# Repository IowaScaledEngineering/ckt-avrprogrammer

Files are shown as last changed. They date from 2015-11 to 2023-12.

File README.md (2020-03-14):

# Iowa Scaled Engineering CKT-AVRPROGRAMMER

The [CKT-AVRPROGRAMMER](https://www.iascaled.com/store/CKT-AVRPROGRAMMER) is
a modification on the various USBtinyISP Atmel/Microchip AVR programmers,
such as the [SparkFun Pocket AVR Programmer](https://www.sparkfun.com/products/9825) 
and [Adafruit USPtinyISP AVR Programmer](https://www.adafruit.com/product/46). 
We wanted a version with the ability to power both 3.3V and 5V targets, and
short protection to avoid taking down the USB chain in the event of a target
short.

https://www.iascaled.com/store/CKT-AVRPROGRAMMER

## Hardware

Hardware portions of this project were created by Nathan Holmes and 
Michael Petersen of Iowa Scaled Engineering, LLC, and licensed under 
the Creative Commons Attribution-ShareAlike License.  Details of this 
license can be found here:
https://creativecommons.org/licenses/by-sa/3.0/us/

Much of this design was inspired by SparkFun's Pocket AVR Programmer, 
which itself is open hardware and licensed under CC ShareAlike:
https://www.sparkfun.com/products/9825

Source files (found in sch/ and sym/ for the schematic and pcb/ for the pcb)
are in gEDA (gschem / pcb) format.

Production versions are archived in the pg/ directory, and include PDFs of
the schematics and PCB files, as well as the actual gerbers used for board
and stencil generation.

## Software

Source code can be found in the src/ subdirectory.  The firmware in the pocket-prog directory originally came from Sparkfun's
Pocket AVR Programmer project on GitHub:

https://github.com/sparkfun/Pocket_AVR_Programmer

This was, in turn, based on the USBtiny by Dick Streefland, and USBtinyISP
by Limor Fried.

http://dicks.home.xs4all.nl/avr/usbtiny/index.html

https://learn.adafruit.com/usbtinyisp

This code, per Dick Streefland's original license, is free software licensed
under the GNU General Public License v2.  For a copy of the GPL v2, see the 
src/LICENSE file.

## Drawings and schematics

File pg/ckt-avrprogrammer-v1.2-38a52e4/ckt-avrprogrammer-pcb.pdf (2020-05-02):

# ckt-avrprogrammer.pcb

# 1. Table of Contents (This Page) Created on Wed Apr 15 09:13:26 2020

# 2. top 3. bottom 4. outline 5. plated-drill 6. unplated-drill 7. componentmask 8. soldermask 9. topsilk 10. bottomsilk 11. toppaste 12. topassembly 13. bottomassembly 14. fab

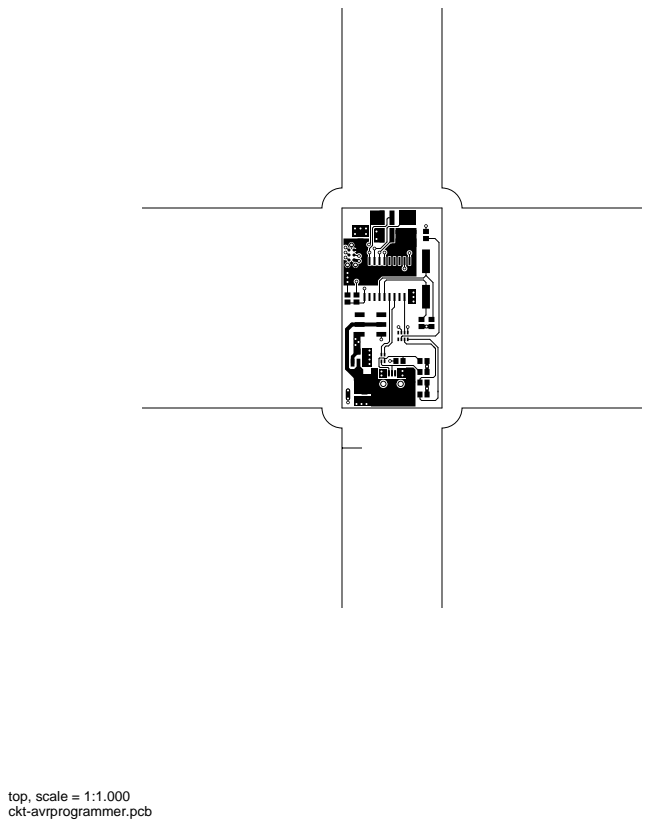
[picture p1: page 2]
top, scale = 1:1.000

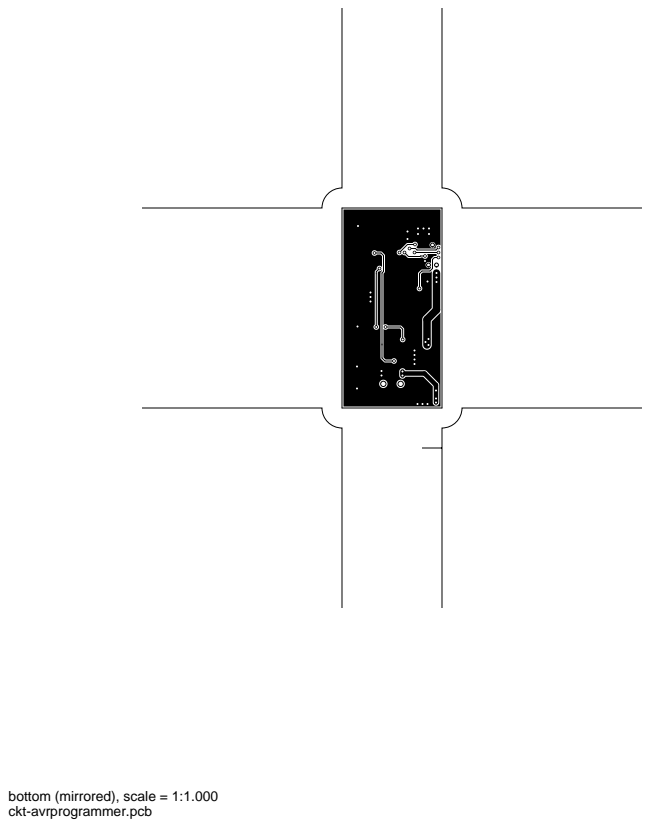
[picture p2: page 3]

bottom (mirrored), scale = 1:1.000

outline, scale = 1:1.000

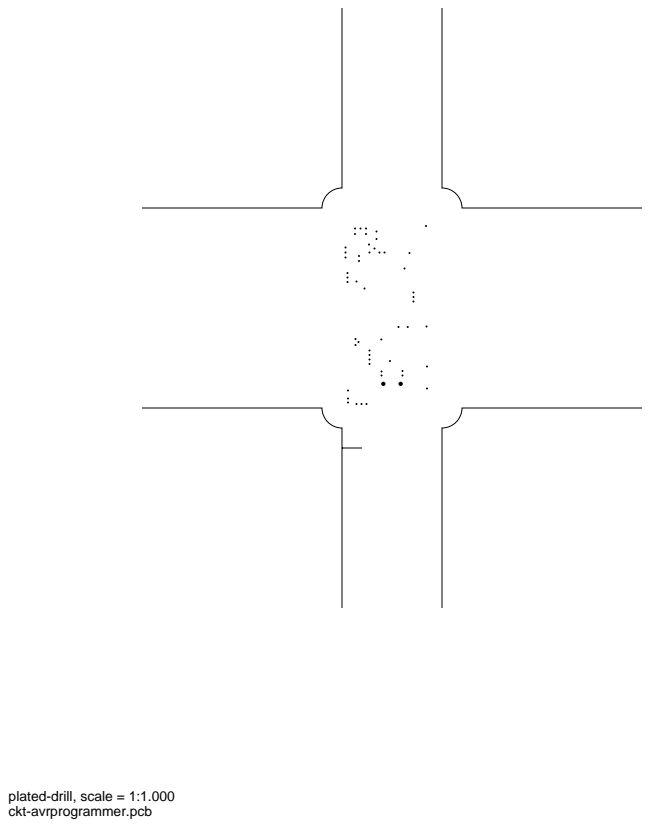
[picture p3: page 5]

plated-drill, scale = 1:1.000

unplated-drill, scale = 1:1.000

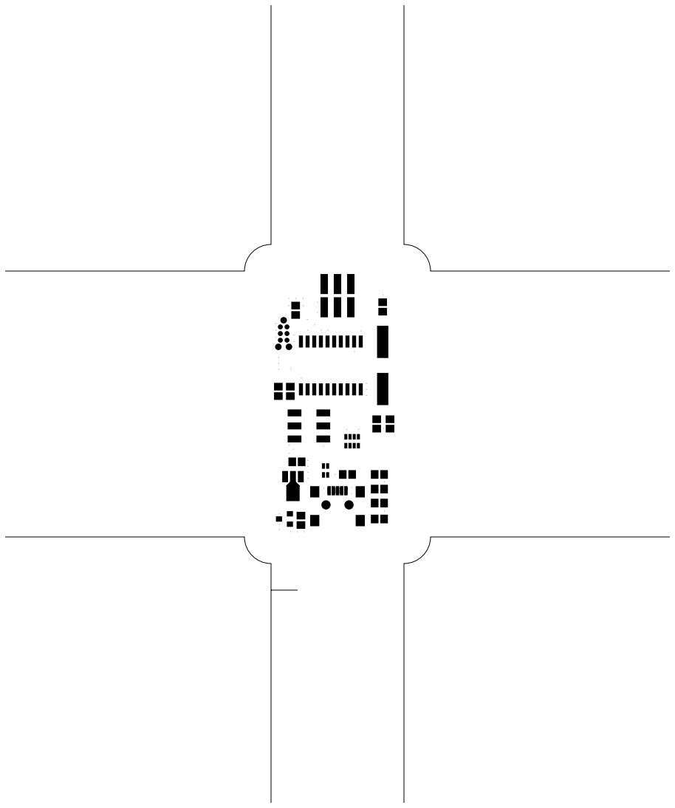
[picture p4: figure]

topmask, scale = 1:1.000

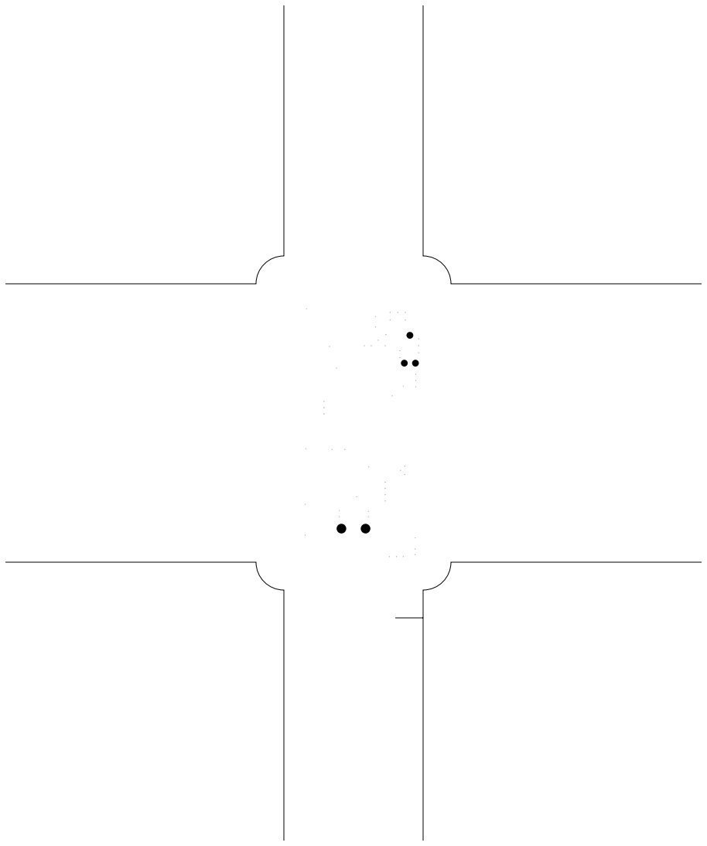
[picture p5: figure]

bottommask (mirrored), scale = 1:1.000

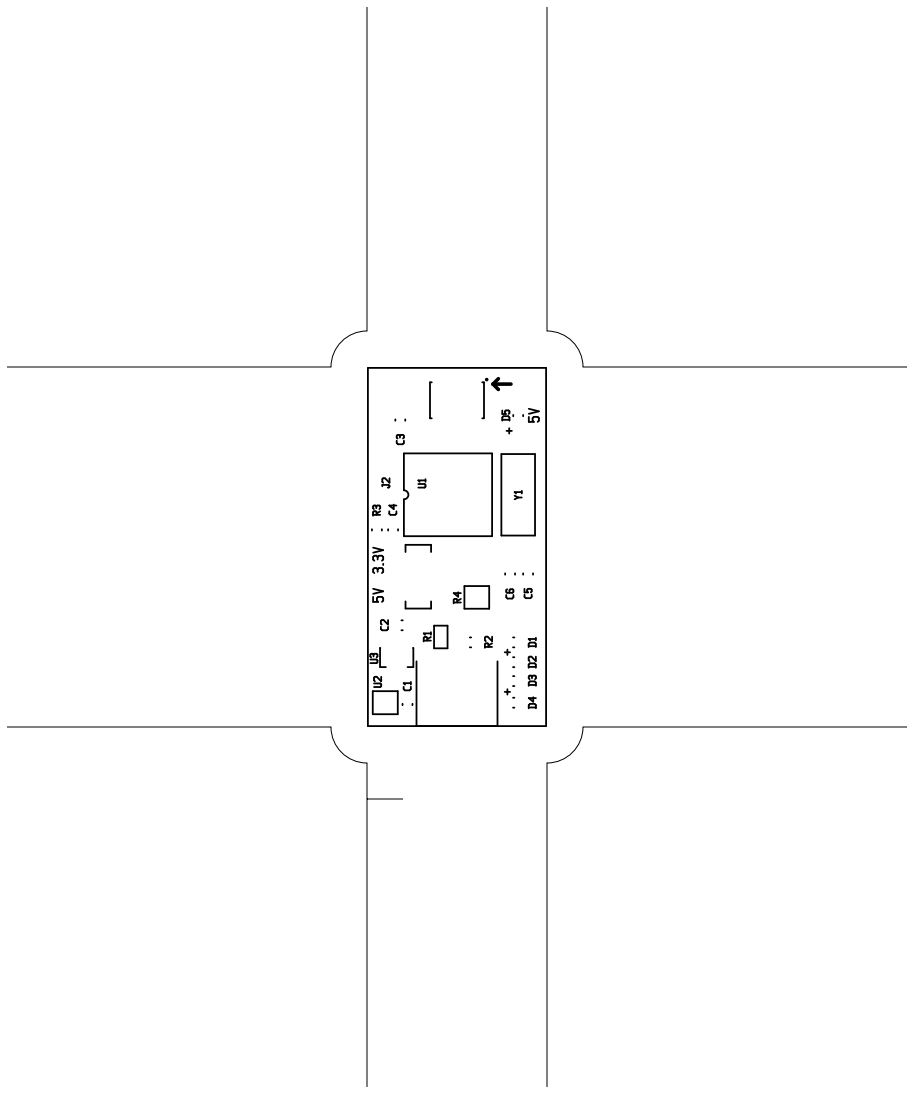
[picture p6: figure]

topsilk, scale = 1:1.000

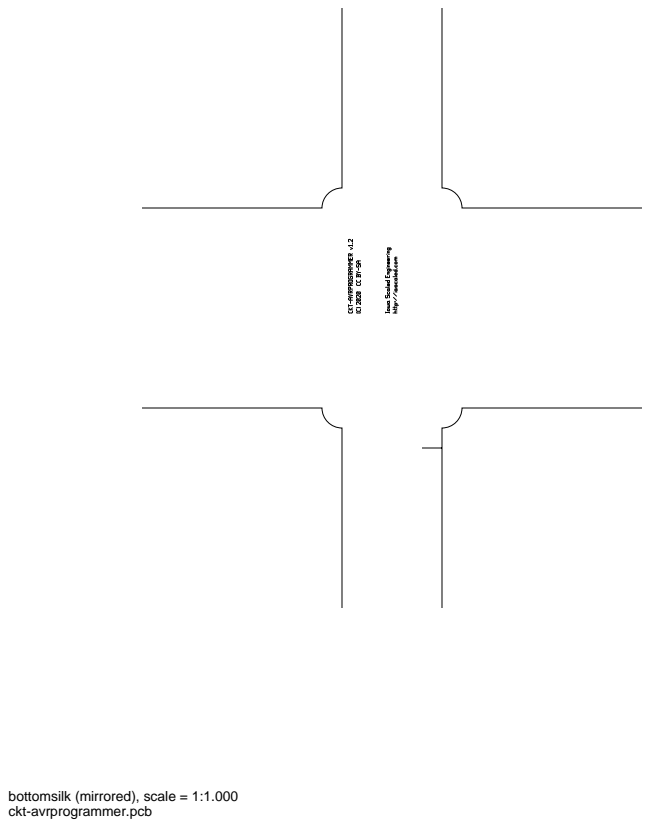
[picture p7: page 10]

bottomsilk (mirrored), scale = 1:1.000

toppaste, scale = 1:1.000

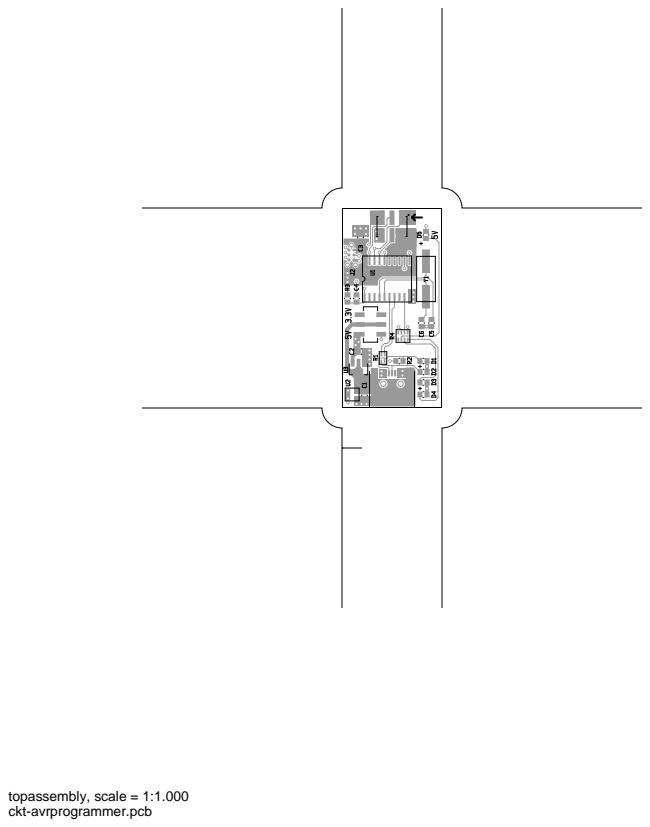
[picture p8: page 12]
topassembly, scale = 1:1.000

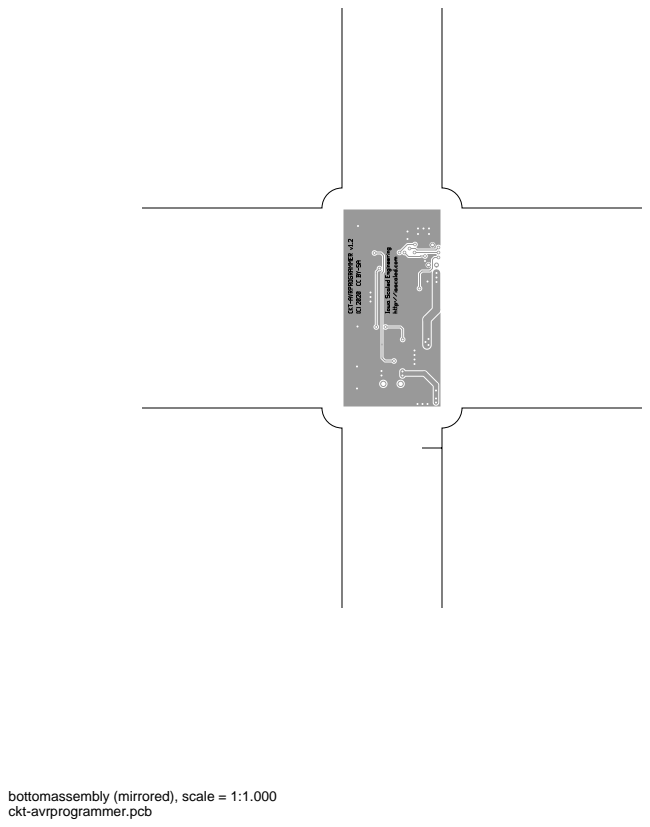
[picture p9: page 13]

bottomassembly (mirrored), scale = 1:1.000

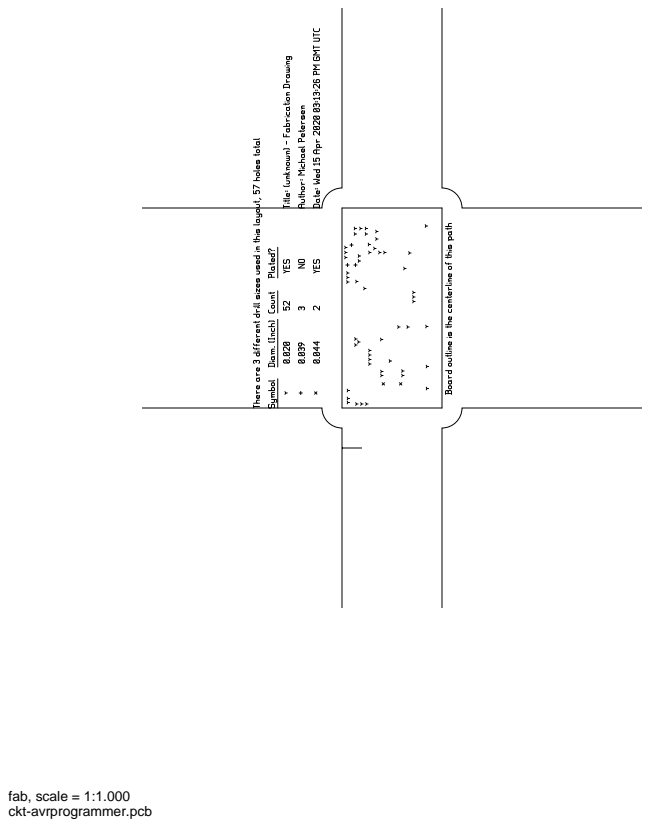
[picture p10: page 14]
fab, scale = 1:1.000

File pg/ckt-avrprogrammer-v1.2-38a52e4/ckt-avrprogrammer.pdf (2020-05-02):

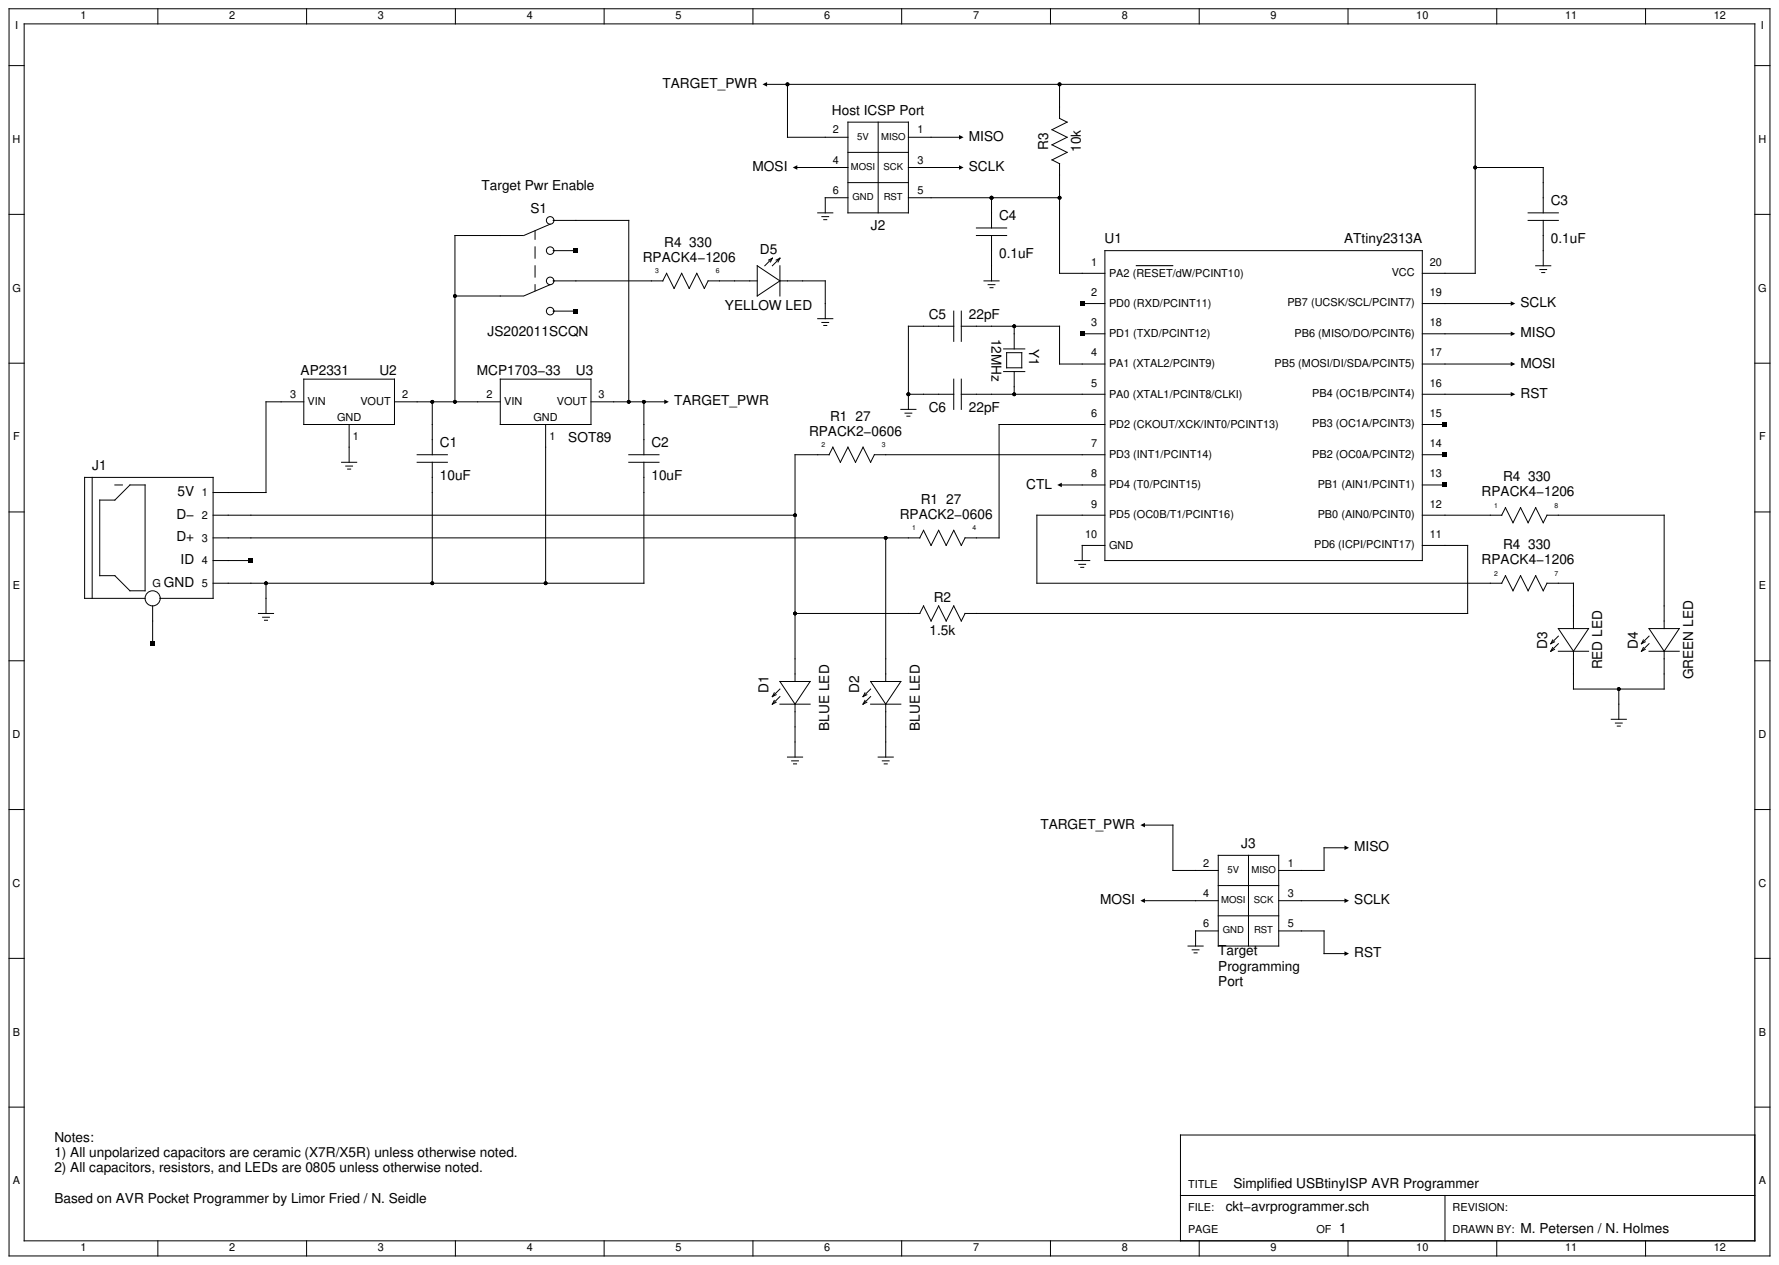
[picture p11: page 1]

8 CTL | 13

Notes:
1) All unpolarized capacitors are ceramic (X7R/X5R) unless otherwise noted.
2) All capacitors, resistors, and LEDs are 0805 unless otherwise noted.

Simplified USBtinyISP AVR Programmer
ckt−avrprogrammer.sch

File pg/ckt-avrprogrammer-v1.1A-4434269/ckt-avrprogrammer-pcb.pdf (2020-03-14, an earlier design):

# ckt-avrprogrammer.pcb

# 1. Table of Contents (This Page) Created on Thu Aug 30 13:28:31 2018

# 2. top 3. bottom 4. outline 5. plated-drill 6. unplated-drill 7. componentmask 8. soldermask 9. topsilk 10. bottomsilk 11. toppaste 12. topassembly 13. bottomassembly 14. fab

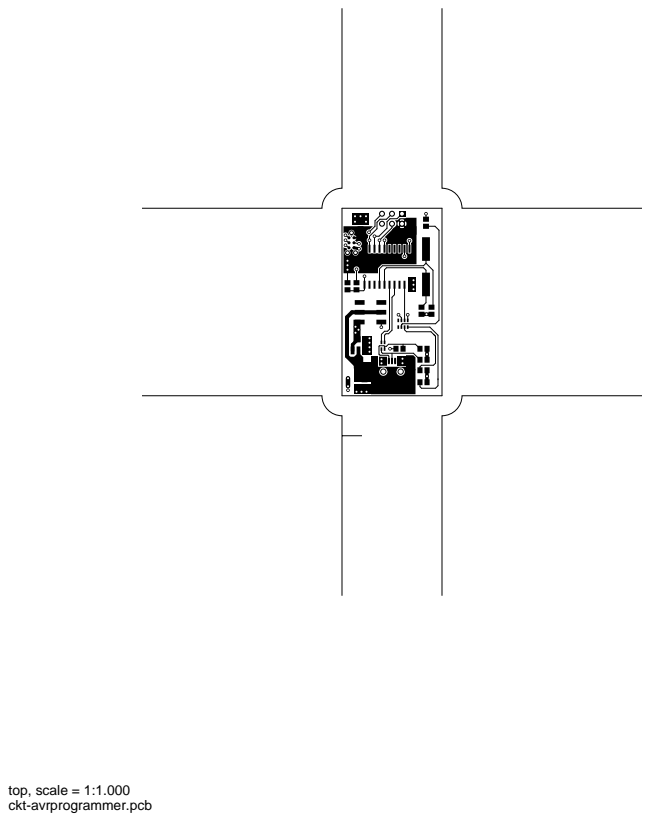
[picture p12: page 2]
top, scale = 1:1.000


bottom (mirrored), scale = 1:1.000

outline, scale = 1:1.000


plated-drill, scale = 1:1.000

unplated-drill, scale = 1:1.000


topmask, scale = 1:1.000


bottommask (mirrored), scale = 1:1.000


topsilk, scale = 1:1.000


bottomsilk (mirrored), scale = 1:1.000

toppaste, scale = 1:1.000

topassembly, scale = 1:1.000


bottomassembly (mirrored), scale = 1:1.000

fab, scale = 1:1.000

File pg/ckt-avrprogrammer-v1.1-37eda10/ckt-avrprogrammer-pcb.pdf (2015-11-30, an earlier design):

# ckt-avrprogrammer.pcb

# 1. Table of Contents (This Page) Created on Mon Nov 30 11:11:34 2015

# 2. top 3. bottom 4. outline 5. plated-drill 6. unplated-drill 7. componentmask 8. soldermask 9. topsilk 10. bottomsilk 11. toppaste 12. topassembly 13. bottomassembly 14. fab

top, scale = 1:1.000


bottom (mirrored), scale = 1:1.000

outline, scale = 1:1.000


plated-drill, scale = 1:1.000

unplated-drill, scale = 1:1.000


topmask, scale = 1:1.000


bottommask (mirrored), scale = 1:1.000


topsilk, scale = 1:1.000


bottomsilk (mirrored), scale = 1:1.000

toppaste, scale = 1:1.000

topassembly, scale = 1:1.000


bottomassembly (mirrored), scale = 1:1.000

fab, scale = 1:1.000

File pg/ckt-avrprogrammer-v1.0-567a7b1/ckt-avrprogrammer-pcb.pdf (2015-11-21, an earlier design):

# ckt-avrprogrammer.pcb

# 1. Table of Contents (This Page) Created on Thu Oct 29 12:01:01 2015

# 2. top 3. bottom 4. outline 5. plated-drill 6. unplated-drill 7. componentmask 8. soldermask 9. topsilk 10. bottomsilk 11. toppaste 12. topassembly 13. bottomassembly 14. fab

top, scale = 1:1.000


bottom (mirrored), scale = 1:1.000

outline, scale = 1:1.000


plated-drill, scale = 1:1.000

unplated-drill, scale = 1:1.000


topmask, scale = 1:1.000


bottommask (mirrored), scale = 1:1.000


topsilk, scale = 1:1.000


bottomsilk (mirrored), scale = 1:1.000

toppaste, scale = 1:1.000

topassembly, scale = 1:1.000


bottomassembly (mirrored), scale = 1:1.000

fab, scale = 1:1.000

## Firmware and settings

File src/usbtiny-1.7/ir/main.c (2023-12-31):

// ======================================================================
// IR receiver and LCD controller with USB interface.
//
// Read IR mark/space patterns from a TSOP1738 on the ICP input pin.
// Mark and space periods are measured in units of 12Mhz/1024, which is
// 85.33 us. Up to 36 periods are stored in a buffer, where they can
// be read via a USB request. The buffer layout and USB requests are
// compatible with the "IgorPlug-USB" device, which is supported by LIRC
// through the "igorplugusb" driver. This implementation should also
// work with that driver. If IgorPlug-USB compatibility is not required,
// the resolution could be improved by reducing SCALING to 9, and you
// could also get rid of the additional endpoint (USBTINY_ENDPOINT).
//
// There are some IR protocols with very long packets length, such as
// the "NEC" protocol (http://www.sbprojects.com/knowledge/ir/nec.htm).
// This protocol uses 67 mark/space periods, which is too much for the
// limited amount of RAM in the ATtiny2313. Simply truncating the
// packet to the amount of available buffer space is not an option,
// because the significant bits are at the end of the packet. Instead,
// a buffer of 36 bytes (IR_MAX) is used, of which the last 16 bytes
// (IR_WRAP) are used as a circular buffer. Because both the address
// (16 periods) and the command code (16 periods) are sent twice (normal
// and inverted), the wrapping will result in a buffer with both the
// device address and the inverted command code. Other IR protocols are
// typically shorter than 36 periods.
//
// 16-bit Timer1 is initialized in normal mode with a clock of 12MHz/8.
// Both the positive and negative edges of the IR input signal on the
// ICP input pin trigger an input capture interrupt, because the edge
// selection is toggled on every interrupt. Output compare register A
// is used for a timeout to detect the end of an IR transmission.
// The timeout value is updated on every edge. When at least 4 edges
// were detected when a timeout occurs, the packet count ir.count is
// incremented and the ir.length byte is set to the packed length. This
// byte is checked when a read request is received via USB to see if a
// packet is available
//
// The two interrupt handlers in this file run for more than 28 cycles,
// so they need to reenable interrupts to allow USB interrupts to be
// handled in time. To avoid nested IR interrupts, the input capture and
// output compare interrupts are disabled before the global interrupt
// flag is set. In the input capture interrupt handler, the interrupts
// are disabled for a maximum of 27, 27 and 27 cycles, and in the output
// compare interrupt handler for 21, 23 and 22 cycles. Unfortunately,
// it was not possible to meet the 28 cycle maximum for the input
// capture interrupt handler without using some inline assembly.
// Because the limits are so tight, the code is fragile, and may break
// for a new gcc version.
//
// The IR receiver is disabled during an IR buffer read, so that a
// packet that is being tranmitted to the host, is not overwritten by
// the next packet. When a transfer is in progress, 'inpos' has a value
// other than 0xff. When the buffer is read completely, the IR receiver
// is reenabled again, but when the next IR packet has already started,
// this packed is discarded by setting 'edges' to 0xff.
//
// There are two USB request codes to control the LCD, one to write
// instructions, and one to write data to the display. OUT transfers
// are used to transfer up to 255 bytes for a single request.
//
// Stack space calculations for gcc-4.1.0 and gcc-4.3.4:
//
//   0  main (stack reset)
//   0      lcd_init (inlined)
//   0      ir_init (inlined)
//   2      usb_init
//   5      usb_poll
//   0          usb_receive (inlined)
//   2              usb_setup
//   5              usb_out
//   3                  lcd_write
//   0                      lcd_read4 (inlined)
//   2                      lcd_write4
//   0          usb_transmit (inlined)
//   4              usb_int
//   2              crc
//
// Maximum stack space is 5+5+3+2=15.
// Total stack usage:
// - USB interrupt:			11 bytes
// - IR input capture interrupt:	12 bytes
// - IR output compare interrupt: 	 7 bytes
// - main():				15 bytes
// The two IR interrupt handler cannot be active simultaneously, so the
// maximum stack space is 15+12+11=38 bytes.
//
// NOTE: The above cycle and stack size figures were obtained by
//       inspecting the code generated by gcc-4.1.0 and gcc-4.3.4.
//       Other compiler versions may generate different code, leading
//       to different figures.
//
// Copyright 2006-2010 Dick Streefland
//
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
#include <avr/io.h>
#include <avr/interrupt.h>
#include "def.h"
#include "usb.h"

// ----------------------------------------------------------------------
// IR receiver definitions
// ----------------------------------------------------------------------

#define	TIMEOUT		10500	// IR transmission timeout in us
#define	IR_MAX		36	// maximum number of IR data bytes
#define	IR_WRAP		16	// wrap area at end (for 67 byte NEC protocol)
#define	SCALING		10	// 9: 42.67 us period, 10: 85.33 us period
#define	LED		(D,5)	// I/O port for LED

enum
{
	// Generic requests
	USBTINY_ECHO,		// echo test
	// IgorPlug-USB requests
	IGORPLUG_CLEAR,		// clear IR data
	IGORPLUG_READ,		// read IR data (wValue: offset)
	// LCD requests
	LCD_INSTR = 20,		// write instructions to LCD (via OUT)
	LCD_DATA,		// write data to LCD (via OUT)
};

static	byte_t	inpos;		// read position for usb_in(), or 0xff
static	byte_t	edges;		// incremented for each edge
static	struct			// IgorPlug-USB compatible data layout
{
	byte_t	length;		// length of data[]
	byte_t	count;		// incremented for each IR packet
	byte_t	offset;		// not used
	byte_t	data[IR_MAX];	// mark/space periods
}		ir;

// ----------------------------------------------------------------------
// LCD definitions
// ----------------------------------------------------------------------

#define	LCD_PRESENT	1	// set to 0 to remove LCD support

#define	DDR		DDRB
#define	PORT		PORTB
#define	PIN		PINB

#define	D4		0
#define	RS		4
#define	RW		5
#define	E		6

#define	MASK_D4		(0xf << D4)
#define	MASK_RS		(1 << RS)
#define	MASK_RW		(1 << RW)
#define	MASK_E		(1 << E)

#ifndef	ICIE1
#define	ICIE1		TICIE1
#endif

// ----------------------------------------------------------------------
// Handler for timer1 input capture interrupt: edge on IR input
// ----------------------------------------------------------------------
ISR(TIMER1_CAPT_vect)
{
	static	uint_t	prev;
	uint_t		stamp;
	byte_t		delta;
	byte_t		e;

	TIMSK = 0;				// disable both IR interrupts
	sei();					// allow USB interrupt
	TCCR1B ^= _BV(ICES1);			// toggle edge detector
	stamp = ICR1;				// get time stamp
	asm volatile(
		"push	%A0\n"			// save stamp
		"push	%B0\n"
		:
		: "w"(stamp), "w"(prev)		// "w"(prev) reduces register usage
	);
	stamp -= prev;				// calculate delta in-place
	stamp += 1 << (SCALING - 3 - 1);	// round
	stamp >>= (SCALING - 3);		// scale
	asm volatile(
		"mov	%0,%A1\n"		// delta = stamp & 0xff
		"pop	%B1\n"
		"pop	%A1\n"			// restore stamp
		: "=r"(delta)
		: "w"(stamp)
	);
	prev  = stamp;
	OCR1A = stamp + 12L * TIMEOUT / 8;	// update timeout value
	cli();					// enter critical region
	e = edges;
	if	( e != 0xff )			// packet should not be ignored?
	{
		if	( e > IR_MAX )		// packet too long for buffer?
		{
			e -= IR_WRAP;		// wrap, don't truncate
		}
		if	( inpos == 0xff )	// update ir only when USB idle
		{
			ir.length = 0;		// discard previous packet
			if	( e > 0 )
			{
				ir.data[e - 1] = delta;
			}
		}
		edges = e + 1;
	}
	sei();					// allow USB interrupt
	SET(LED);				// switch LED on
	e = _BV(OCIE1A) | _BV(ICIE1);
	asm volatile("" :: "r"(e));		// force evaluation of "e"
	cli();
	TIMSK = e;				// reenable IR interrupts
}

// ----------------------------------------------------------------------
// Handler for timer1 output compare A interrupt: IR transmission timeout
// ----------------------------------------------------------------------
ISR(TIMER1_COMPA_vect)
{
	TIMSK = 0;				// disable both IR interrupts
	sei();					// allow USB interrupt
	CLR(LED);				// switch LED off
	cli();					// enter critical region
	if	(  edges >= 4			// at least two pulses (NEC)
		&& edges != 0xff		// packet should not be ignored
		&& inpos == 0xff		// update ir only when USB idle
		)
	{
		ir.count++;
		ir.length = edges - 1;		// new packet is complete
	}
	edges = 0;
	sei();					// allow USB interrupt
	TCCR1B &= ~_BV(ICES1);			// reset to negative edge
	cli();
	TIMSK = _BV(OCIE1A) | _BV(ICIE1);	// reenable IR interrupts
}

// ----------------------------------------------------------------------
// Initialize the IR receiver.
// ----------------------------------------------------------------------
static	void	ir_init ( void )
{
	OUTPUT(LED);
	TCCR1B = _BV(ICNC1)	// noise canceler, trigger on negative edge
	       | _BV(CS11);	// clock source clk/8
	TIMSK  = _BV(OCIE1A)	// output compare 1A match interrupt enable
	       | _BV(ICIE1);	// input capture 1 interrupt enable
}

#if	LCD_PRESENT
// ----------------------------------------------------------------------
// Delay <count> times 100 microseconds.
// ----------------------------------------------------------------------
__attribute__((noinline))
static	void	lcd_delay100u ( byte_t count )
{
	asm volatile(
		"0:	ldi	r25, 240\n"
		"1:	rjmp	2f\n"
		"2:	dec	r25\n"
		"	brne	1b\n"	// 240 * 5 cycles = 100us
		"	dec	r24\n"
		"	brne	0b\n"
	);
}

// ----------------------------------------------------------------------
// Write 4 bits to the LCD.
// ----------------------------------------------------------------------
__attribute__((noinline))
static	void	lcd_write4 ( byte_t data )
{
	PORT = (PORT & ~ MASK_D4) | (data << D4);
	PORT |= MASK_E;			// E high period: > 230ns
	DDR  = MASK_RS | MASK_RW | MASK_E | MASK_D4; // Dx setup time: > 80ns
	PORT &= ~ MASK_E;		// hold time: > 10ns
	DDR  = MASK_RS | MASK_RW | MASK_E;
}

// ----------------------------------------------------------------------
// Read 4 bits from the LCD.
// ----------------------------------------------------------------------
__attribute__((always_inline))
static	inline	byte_t	lcd_read4 ( void )
{
	byte_t	save;
	byte_t	data;

	save = PORT;
	PORT = MASK_RW;			// address setup time: > 40ns
	PORT |= MASK_E;			// E high period: > 230ns
	asm volatile("rjmp 0f\n0:");
	data = (PIN & MASK_D4) >> D4;	// data access time: > 160ns
	PORT = save;
	return data;
}

// ----------------------------------------------------------------------
// Write a byte to the LCD.
// ----------------------------------------------------------------------
static	void	lcd_write ( byte_t b )
{
	byte_t	h;

	do
	{
		h = lcd_read4();
		(void) lcd_read4();
	} while	( h & 0x08 );
	lcd_write4( b >> 4 );
	lcd_write4( b & 15 );
}

// ----------------------------------------------------------------------
// Initialize the LCD.
// ----------------------------------------------------------------------
static	void	lcd_init ( void )
{
	DDR = MASK_RS | MASK_RW | MASK_E;
	PORT = 0;
	//lcd_delay100u( 150 );	-- skipped because of RESET delay
	lcd_write4( 3 );
	lcd_delay100u( 41 );
	lcd_write4( 3 );
	lcd_delay100u( 1 );
	lcd_write( 0x32 );	// switch to 4-bit mode
	lcd_write( 0x28 );	// function set: 4-bit mode, two lines
	lcd_write( 0x01 );	// clear display
	lcd_write( 0x06 );	// entry mode: increment, no shift
	lcd_write( 0x0c );	// display control: on, no cursor
}
#endif	/* LCD_PRESENT */

// ----------------------------------------------------------------------
// Handle a non-standard SETUP packet.
// ----------------------------------------------------------------------
extern	byte_t	usb_setup ( byte_t data[8] )
{
	byte_t	req;
	byte_t	r;

	r = 0;

	// Generic requests
	req = data[1];
	if	( req == USBTINY_ECHO )
	{
		r = 8;
	}

	// IgorPlug-USB requests
	if	( req == IGORPLUG_CLEAR )
	{
		ir.length = 0;
		inpos = 0xff;
	}
	if	( req == IGORPLUG_READ )
	{
		cli();
		if	( ir.length > 0 )
		{
			inpos = data[2];
			r = 0xff;	// call usb_in() to get the data
		}
		else
		{
			data[0] = 0;
			r = 1;
		}
		sei();
	}

	// LCD requests
	if	( req == LCD_INSTR )
	{
		PORT &= ~ MASK_RS;	// data will be received by usb_out()
	}
	if	( req == LCD_DATA )
	{
		PORT |= MASK_RS;	// data will be received by usb_out()
	}

	return r;
}

// ----------------------------------------------------------------------
// Handle an IN packet.
// ----------------------------------------------------------------------
extern	byte_t	usb_in ( byte_t* data, byte_t len )
{
	byte_t	n;
	byte_t	max;

	max = ir.length + 3;
	n = 0;
	while	( n < len )
	{
		if	( inpos >= max )	// end of packet?
		{
			cli();
			if	( edges )	// next packet already started?
			{
				edges = 0xff;	// ignore remainder of packet
			}
			inpos = 0xff;		// reenable receiver
			sei();
			break;
		}
		data[n++] = (& ir.length)[inpos++];
	}
	return n;
}

// ----------------------------------------------------------------------
// Handle an OUT packet.
// ----------------------------------------------------------------------
extern	void	usb_out ( byte_t* data, byte_t len )
{
#if	LCD_PRESENT
	while	( len )
	{
		lcd_write( *data++ );
		len--;
	}
#endif	/* LCD_PRESENT */
}

// ----------------------------------------------------------------------
// Main
// ----------------------------------------------------------------------
extern	int	main ( void )
{
	SPL = (RAMEND & 0xff);			// drop return address of main
	inpos = 0xff;
#if	LCD_PRESENT
	lcd_init();
#endif	/* LCD_PRESENT */
	ir_init();
	usb_init();
	for	( ;; )
	{
		usb_poll();
	}
}

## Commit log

2015-02-11 Initial start of improved usbtinyisp project
    [usbtinyisp-improved.sch]
2015-02-12 Draft first cut of the improved programmer
    [usbtinyisp-improved.sch]
2015-02-12 Rename project schematic to match github name
    [ckt-avrprogrammer.sch]
2015-02-18 Update crystal in schematic
    [ckt-avrprogrammer.sch]
2015-03-11 Work to make schematic go to pcb cleanly
    [ckt-avrprogrammer.sch]
2015-03-11 fix ground netlist issue with symbol
2015-03-11 More updates to make the pcb
    [ckt-avrprogrammer.sch]
2015-03-11 Change pin definitions on mosfet symbol to match our sot23
    [ckt-avrprogrammer.sch]
2015-03-11 Add the start of a pcb
2015-03-11 More work on pcb layout
    [ckt-avrprogrammer.sch]
2015-03-12 First finished cut of the programmer
    [ckt-avrprogrammer.sch]
2015-09-05 Simplified version for 3.3V support
    [ckt-avrprogrammer.sch]
2015-09-05 Changed power LED to D7
    [ckt-avrprogrammer.sch]
2015-09-09 Removed D7, changed D4 to green. Changed LEDs to 0805. Changed R5/R6 to 330. Fixed 74AHC125 footprint.
    [ckt-avrprogrammer.sch]
2015-09-10 Very simplified version
    [ckt-avrprogrammer.sch]
2015-09-10 Minor cleanup
    [ckt-avrprogrammer.sch]
2015-09-15 Layout complete
    [ckt-avrprogrammer.sch]
2015-09-15 Added outline, beefed up power trace
2015-09-24 Swapped in SMT USB connector.
    [ckt-avrprogrammer.sch]
2015-09-25 Updated USB footprint, based on latest drawing
    [ckt-avrprogrammer.sch]
2015-10-22 Add some copper around the USB mounting lugs to give the whole thing better adhesion
2015-11-19 Fix to pull up D- rather than D+, better for making low speed device Add pin 1 mark to program port
    [ckt-avrprogrammer.sch]
2015-11-19 Put in the first PG, even though it doesn't work
    [ckt-avrprogrammer.GBL, ckt-avrprogrammer.GBO, ckt-avrprogrammer.GBS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]
2015-11-30 Add new 1.1 pg to fix the USB pull-up issue
    [ckt-avrprogrammer.bottom.gbr, ckt-avrprogrammer.bottommask.gbr, ckt-avrprogrammer.bottompaste.gbr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]
2018-03-24 Added firmware files
    [ir.sch]
2018-03-24 Fix compile to use Arduino 1.0.5
2018-04-09 Added ISE VID/PID
2018-08-30 Reduced solder paste on J1
2018-08-30 Closed metal around mounting tabs on J1
2020-03-14 Reduced solderpaste on USB connector
    [ckt-avrprogrammer.bottom.gbr, ckt-avrprogrammer.bottommask.gbr, ckt-avrprogrammer.bottompaste.gbr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]
2020-04-14 Changed to SMT header
    [ckt-avrprogrammer.sch]
2020-04-15 Sent to fab 4/15/2020
    [ckt-avrprogrammer.bottom.gbr, ckt-avrprogrammer.bottommask.gbr, ckt-avrprogrammer.bottompaste.gbr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]
2020-04-23 Added usbtiny-1.7 code
    [ir.sch, spi.sch]

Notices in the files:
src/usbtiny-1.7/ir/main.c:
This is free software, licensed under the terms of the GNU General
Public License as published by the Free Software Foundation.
